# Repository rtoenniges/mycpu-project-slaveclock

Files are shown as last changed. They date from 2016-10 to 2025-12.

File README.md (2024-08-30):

# MyCPU_PRO_SCC
An extension for the [MyCPU](http://www.mycpu.eu/) from Dennis Kuschel to get the timesignal DCF77 and control a slave clock (https://en.wikipedia.org/wiki/Slave_clock)

## Hardware
- External module (Basic board)
- Rack extension (Clock control & DCF77 signal converting)

## Software
- scc.asm (Main program)
- sl60dcf77.asm (Library for DCF77 decoding (Can be found at https://github.com/rtoenniges/MyCPU_LIB_DCF77))

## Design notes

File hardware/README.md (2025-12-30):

# Hardware
## External module (Basic board without DCF77-Input)
This board only generates the alternating current to drive the clock.

## Rack Extension (DCF77-Input and slave-clock control)
This board is connected directly to the MyCPU-Backplane Bus.
It provides support to connect a DCF77-Receiver and generates the alternating
current to drive the clock.
Also it displays the status of the time synchronization and the active clock output.

**If you use this board and you have set the adress jumpers to the default position, you
have to change the "OUTPUT" declaration in "scc.asm" to '3500h'!**

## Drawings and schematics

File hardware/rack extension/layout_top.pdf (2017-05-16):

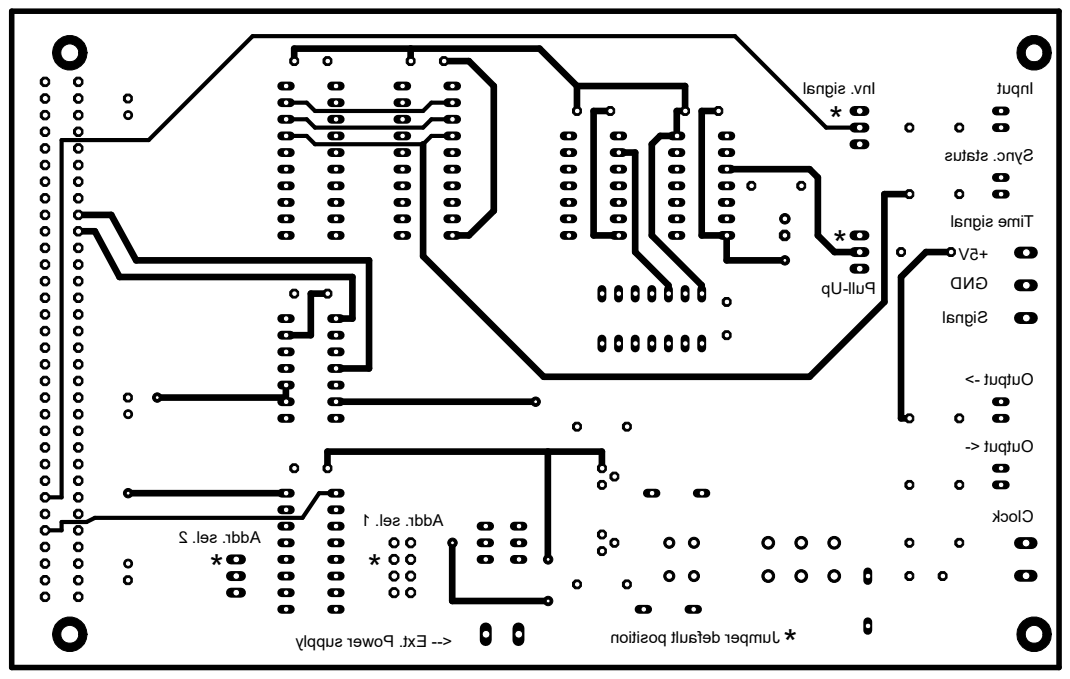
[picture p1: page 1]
Addr. sel. 1; Addr. sel. 2; Clock; Time signal; Pull-Up; Sync. status; Output ->; Output <-; GND; Signal

Inv. signal Input

* <-- Ext. Power supply

Jumper default position

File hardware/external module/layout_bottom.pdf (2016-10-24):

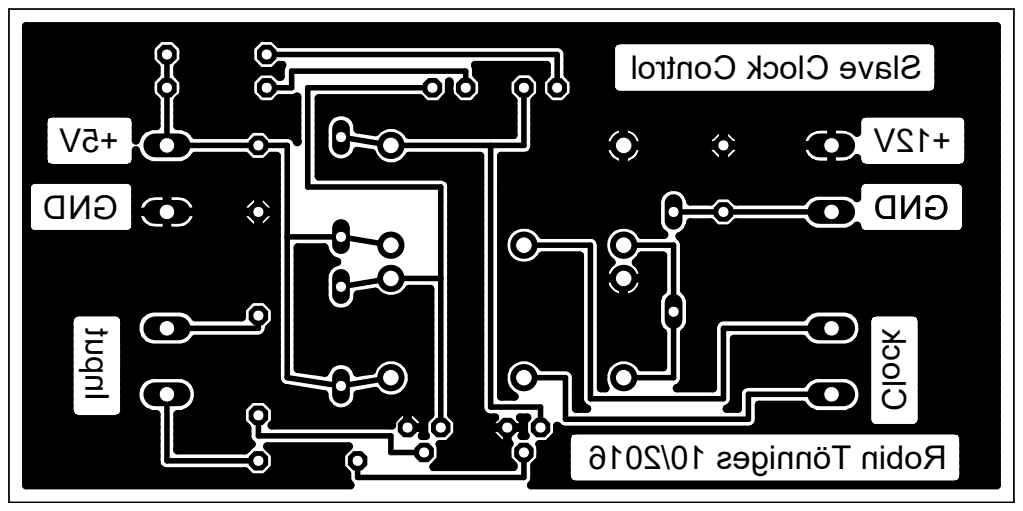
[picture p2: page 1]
+5V GNDInput; GND; +12VClock; Robin Tönniges 10/2016

Slave Clock Control

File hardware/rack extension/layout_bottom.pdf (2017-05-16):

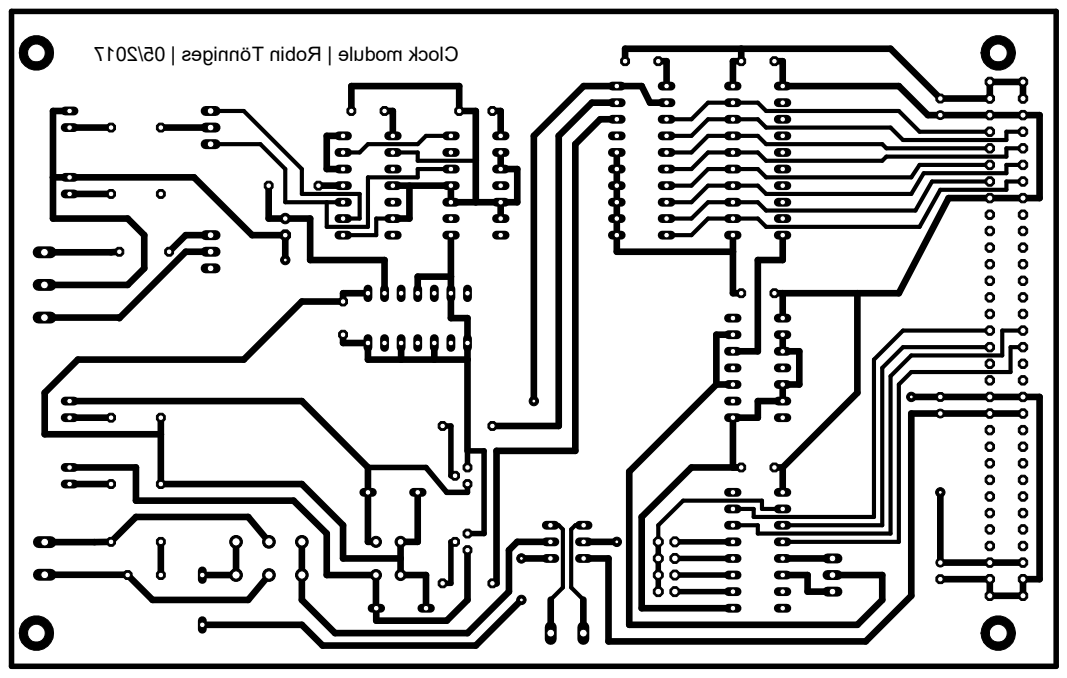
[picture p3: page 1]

Clock module | Robin Tönniges | 05/2017

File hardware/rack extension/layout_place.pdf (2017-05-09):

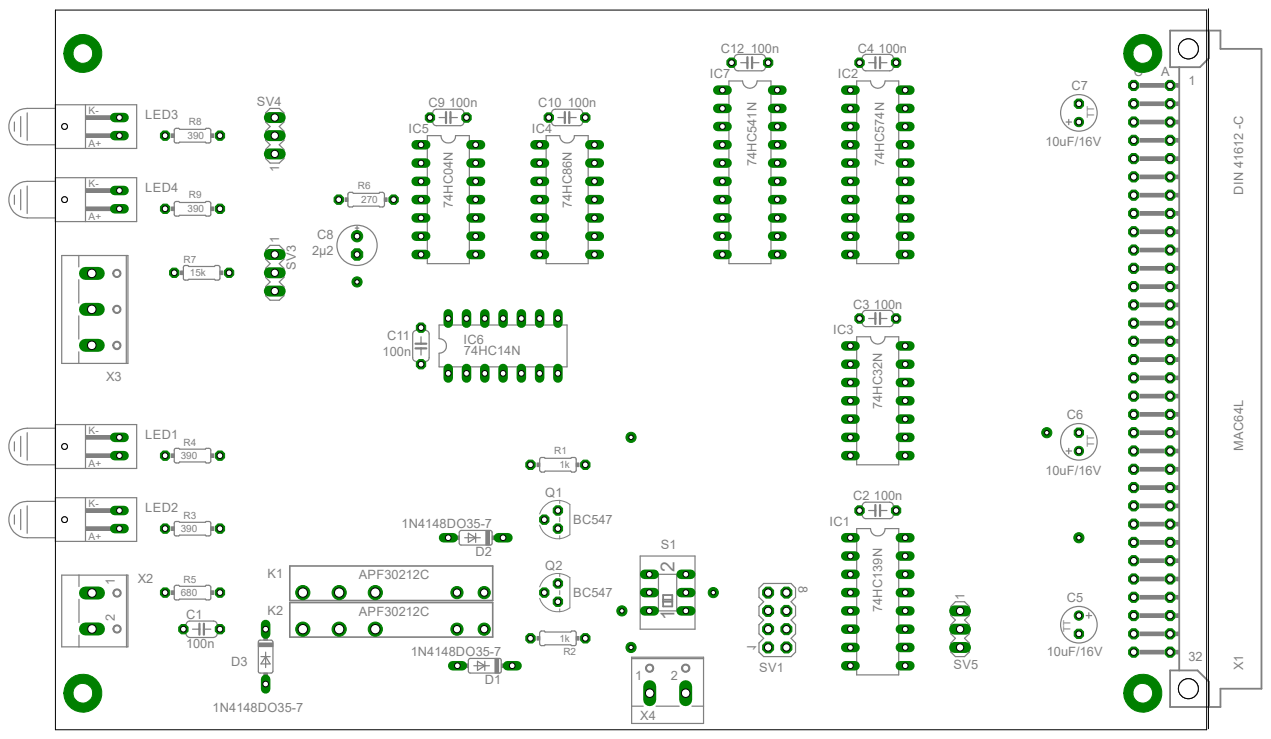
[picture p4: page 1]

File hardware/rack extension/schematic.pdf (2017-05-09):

e

## DCF77

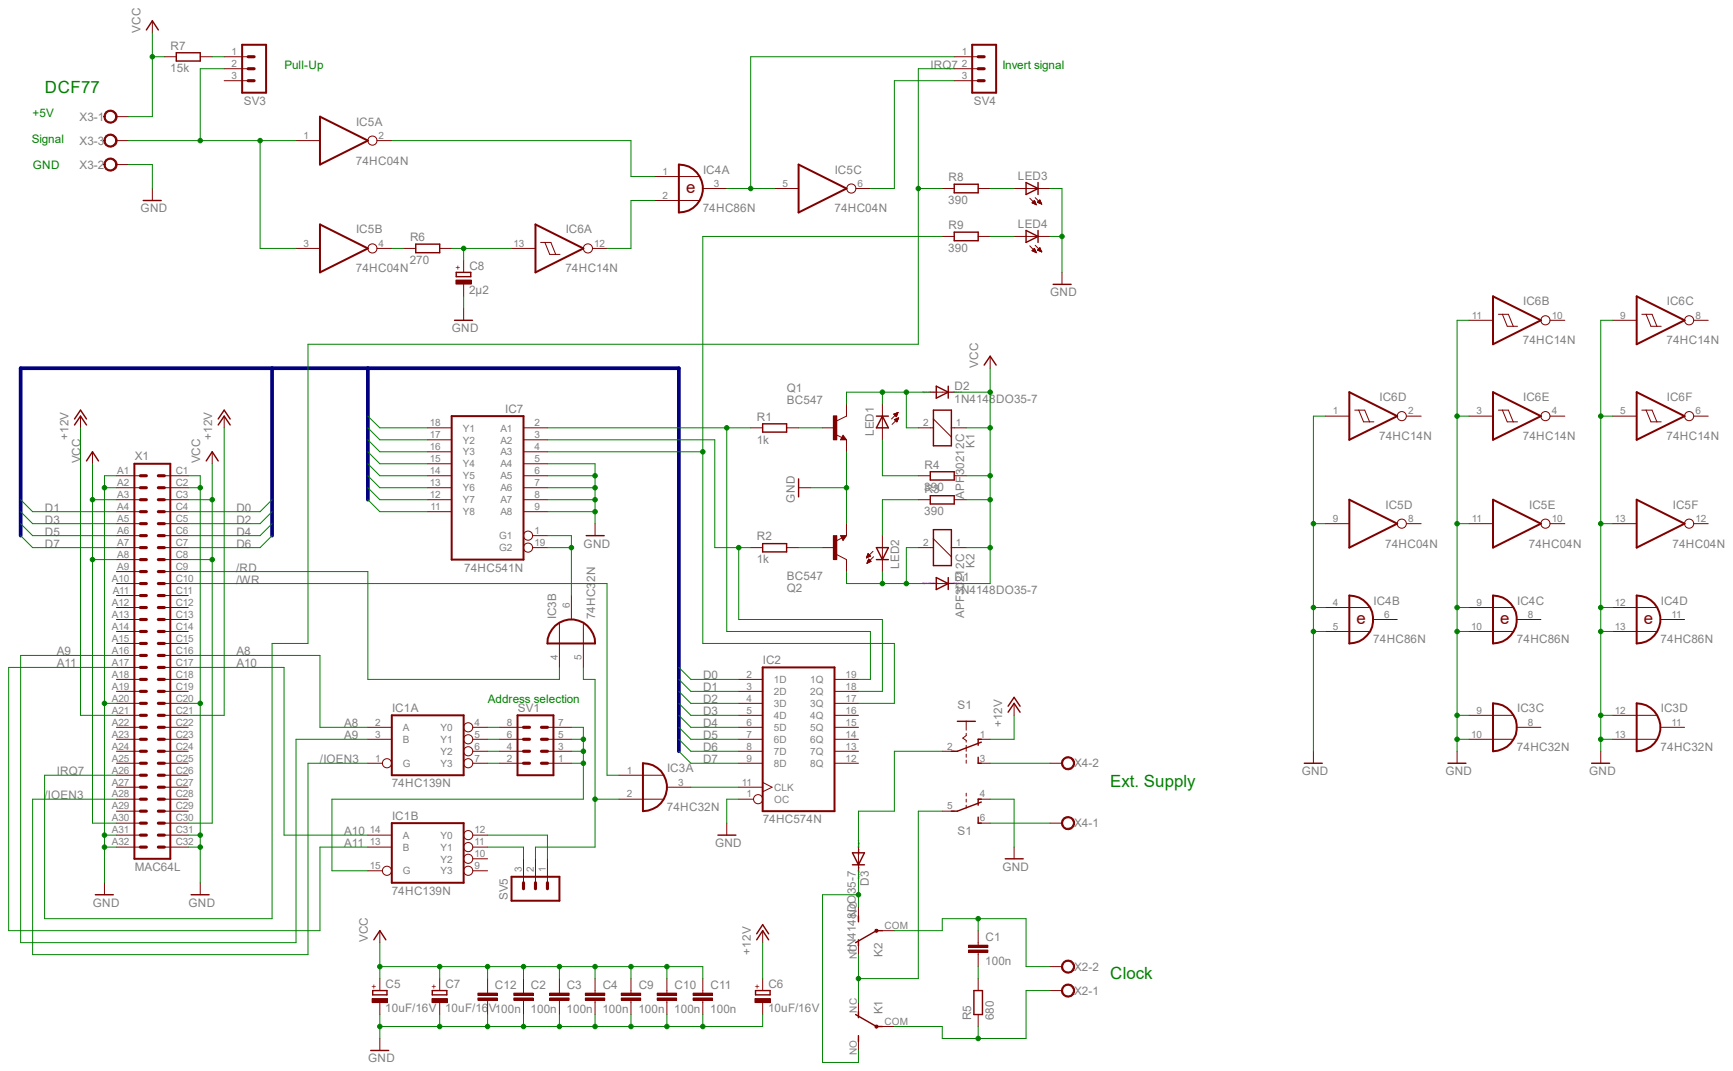
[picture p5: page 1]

C10 | /WR
C11 C12 C13 C14 C15 C16

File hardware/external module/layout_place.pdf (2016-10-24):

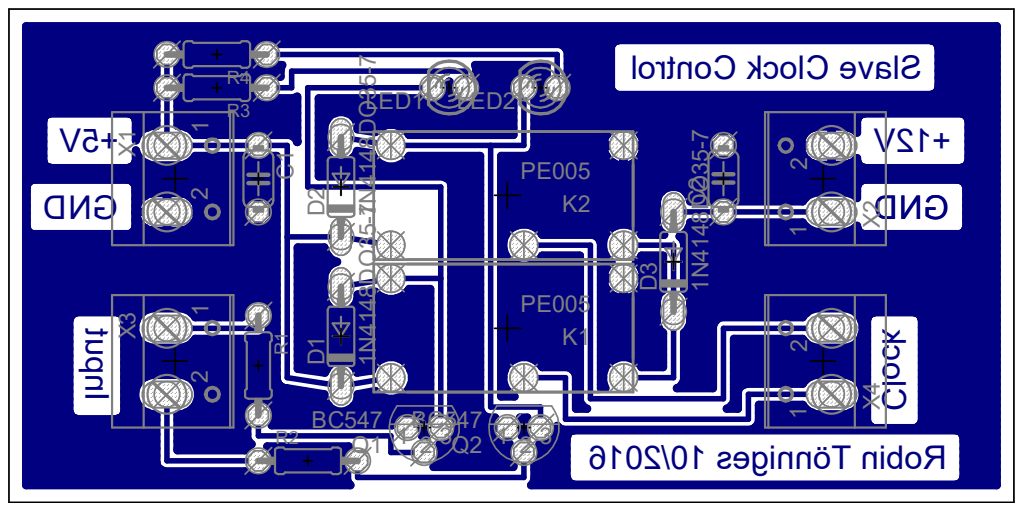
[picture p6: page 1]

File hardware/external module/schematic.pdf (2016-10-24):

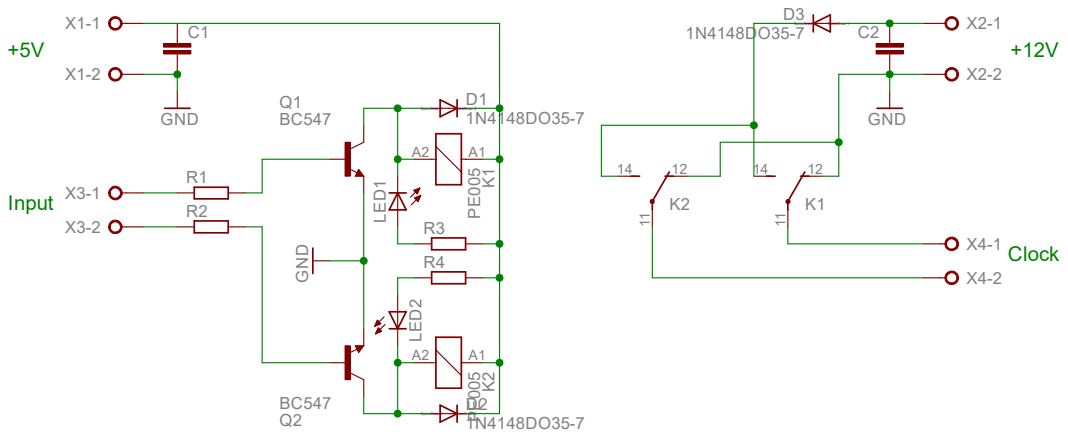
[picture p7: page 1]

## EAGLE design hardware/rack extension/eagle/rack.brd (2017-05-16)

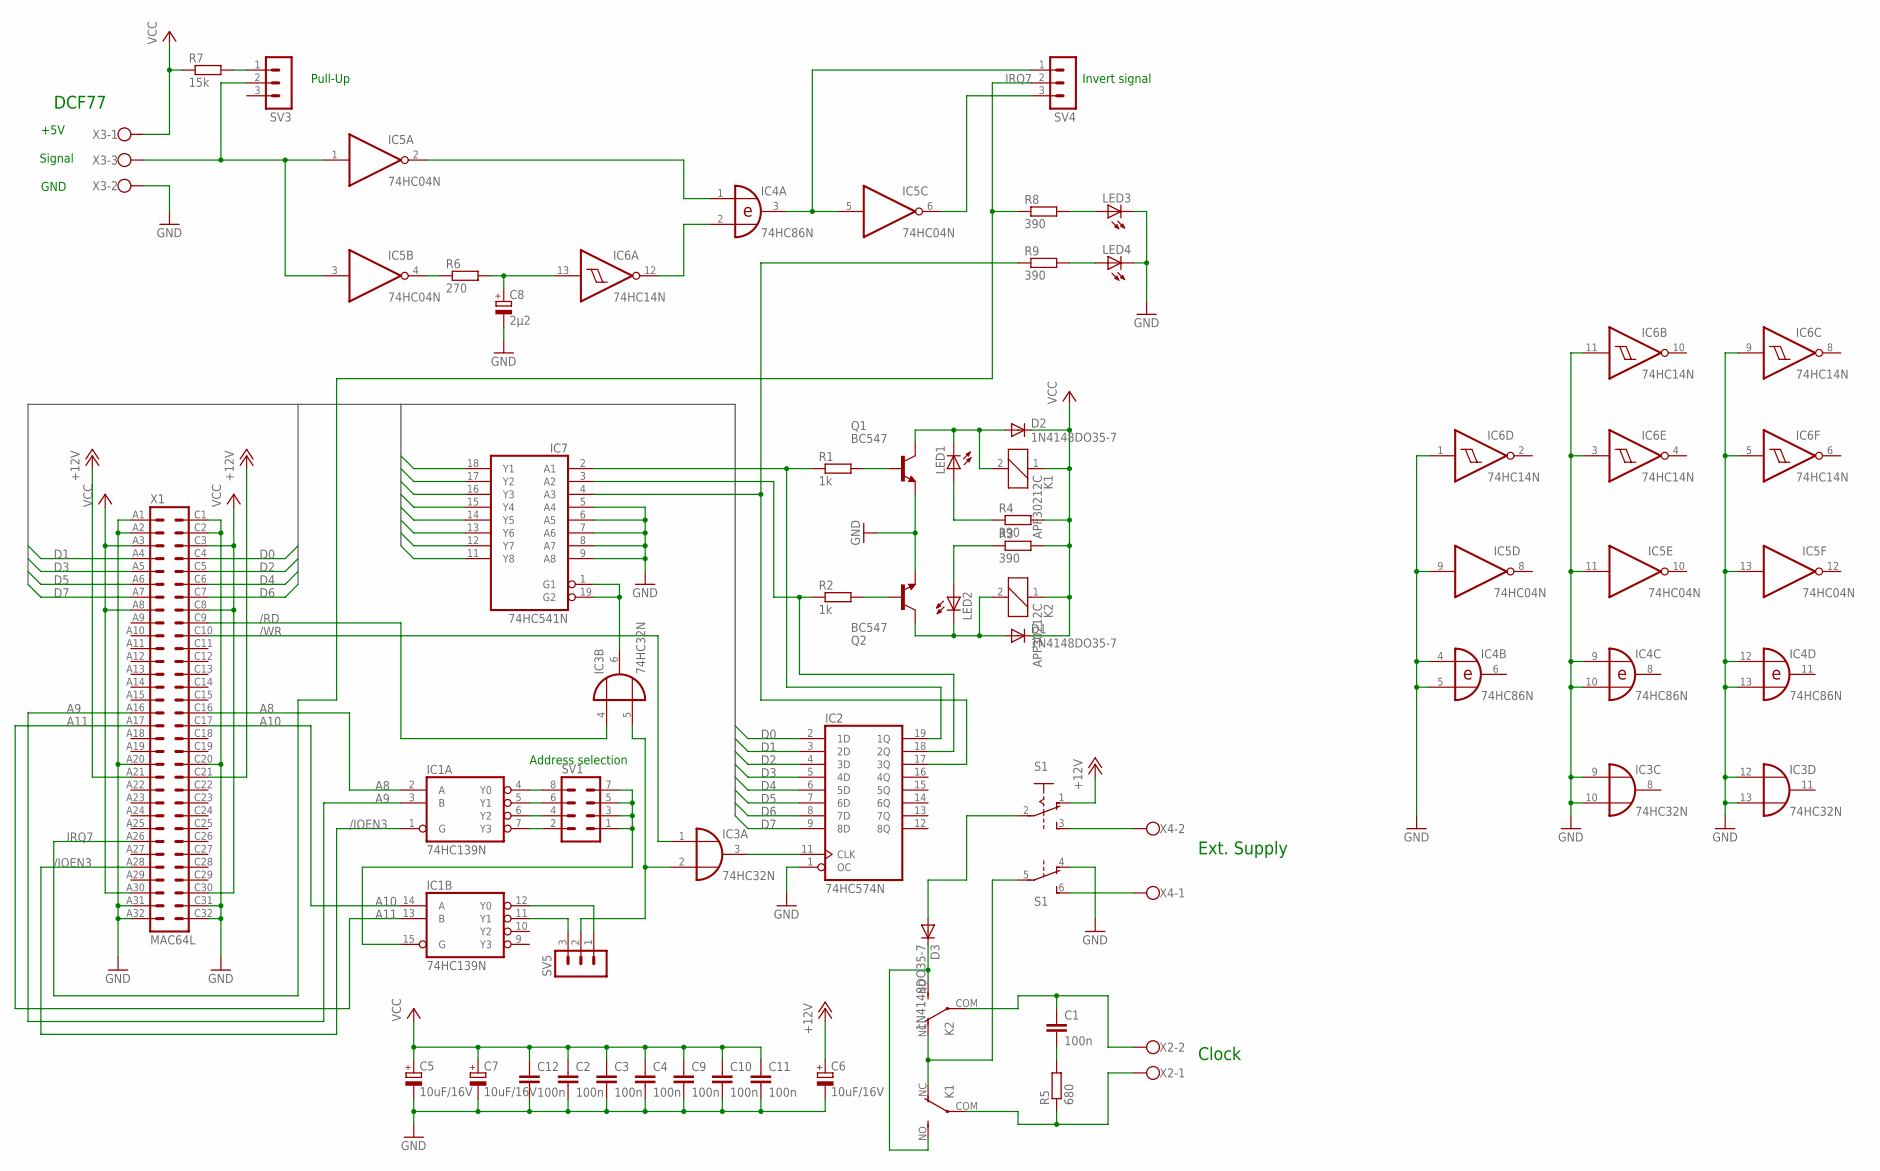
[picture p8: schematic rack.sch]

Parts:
C1, C2, C3, C4, C9, C10, C11, C12: 100n; C050-024X044
C5, C6, C7: 10uF/16V; TT2D5
C8: 2µ2; E2,5-6E
D1, D2, D3: 1N4148DO35-7; DO35-7
IC1: 74HC139N; DIL16
IC2: 74HC574N; DIL20
IC3: 74HC32N; DIL14
IC4: 74HC86N; DIL14
IC5: 74HC04N; DIL14
IC6: 74HC14N; DIL14
IC7: 74HC541N; DIL20
K1, K2: APF30212C
LED1, LED2, LED3, LED4: LEDB155; Q62902-B155
Q1, Q2: BC547; TO92
R1, R2: 1k; 0204/7
R3, R4, R8, R9: 390; 0204/7
R5: 680; 0204/7
R6: 270; 0204/7
R7: 15k; 0204/7
S1: A68-A31
SV1: MA04-2
SV3, SV4, SV5: MA03-1
X1: MAC64L
X2, X4: W237-102
X3: W237-103

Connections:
+12V: C6.+, S1.1 (O), X1.A21, X1.C21
/IOEN3: IC1.1 (G), X1.A28
/RD: IC3.4 (I0), X1.C9
/WR: IC3.1 (I0), X1.C10
A8: IC1.2 (A), X1.C16
A9: IC1.3 (B), X1.A16
A10: IC1.14 (A), X1.C17
A11: IC1.13 (B), X1.A17
D0: IC2.2 (1D), IC7.18 (Y1), X1.C4
D1: IC2.3 (2D), IC7.17 (Y2), X1.A4
D2: IC2.4 (3D), IC7.16 (Y3), X1.C5
D3: IC2.5 (4D), IC7.15 (Y4), X1.A5
D4: IC2.6 (5D), IC7.14 (Y5), X1.C6
D5: IC2.7 (6D), IC7.13 (Y6), X1.A6
D6: IC2.8 (7D), IC7.12 (Y7), X1.C7
D7: IC2.9 (8D), IC7.11 (Y8), X1.A7
GND: C2.2, C3.2, C4.2, C5.-, C6.-, C7.-, C8.-, C9.2, C10.2, C11.2, C12.2, IC1.8 (GND), IC2.1 (OC), IC2.10 (GND), IC3.7 (GND), IC3.9 (I0), IC3.10 (I1), IC3.12 (I0), IC3.13 (I1), IC4.4 (I0), IC4.5 (I1), IC4.7 (GND), IC4.9 (I0), IC4.10 (I1), IC4.12 (I0), IC4.13 (I1), IC5.7 (GND), IC5.9 (I), IC5.11 (I), IC5.13 (I), IC6.1 (I), IC6.3 (I), IC6.5 (I), IC6.7 (GND), IC6.9 (I), IC6.11 (I), IC7.5 (A4), IC7.6 (A5), IC7.7 (A6), IC7.8 (A7), IC7.9 (A8), IC7.10 (GND), LED3.K (C), LED4.K (C), Q1.1 (E), Q2.1 (E), S1.4 (O), X1.A1, X1.A2, X1.A20, X1.A31, X1.A32, X1.C1, X1.C2, X1.C20, X1.C31, X1.C32, X3.2
IRQ7: R8.1, SV4.2, X1.A26
unnamed: IC1.4 (Y0), SV1.8
unnamed: IC1.5 (Y1), SV1.6
unnamed: IC1.6 (Y2), SV1.4
unnamed: IC1.7 (Y3), SV1.2
unnamed: IC2.17 (3Q), IC7.4 (A3), R9.1
unnamed: IC1.11 (Y1), SV5.3
unnamed: IC1.12 (Y0), SV5.1
unnamed: IC1.15 (G), SV1.1, SV1.3, SV1.5, SV1.7
unnamed: IC2.11 (CLK), IC3.3 (O)
unnamed: Q1.2 (B), R1.2
unnamed: IC2.19 (1Q), IC7.2 (A1), R1.1
unnamed: IC2.18 (2Q), IC7.3 (A2), R2.1
unnamed: Q2.2 (B), R2.2
unnamed: D2.A, K1.2, LED1.K (C), Q1.3 (C)
unnamed: C1.2, R5.2
unnamed: D1.A, K2.2, LED2.K (C), Q2.3 (C)
unnamed: C1.1, K2.COM, X2.2
unnamed: LED1.A, R4.1
unnamed: LED2.A, R3.1
unnamed: K1.COM, R5.1, X2.1
unnamed: D3.C, K1.NO (S), K2.NO (S)
unnamed: IC5.4 (O), R6.1
unnamed: C8.+, IC6.13 (I), R6.2
unnamed: IC4.1 (I0), IC5.2 (O)
unnamed: IC4.2 (I1), IC6.12 (O)
unnamed: IC4.3 (O), IC5.5 (I), SV4.1
unnamed: K1.NC (O), K2.NC (O), S1.5
unnamed: R7.2, SV3.1
unnamed: IC5.1 (I), IC5.3 (I), SV3.2, X3.3
unnamed: IC5.6 (O), SV4.3
unnamed: LED3.A, R8.2
unnamed: S1.3 (S), X4.2
unnamed: S1.6 (S), X4.1
unnamed: D3.A, S1.2
unnamed: IC3.6 (O), IC7.1 (G1), IC7.19 (G2)
unnamed: IC3.2 (I1), IC3.5 (I1), SV5.2
unnamed: LED4.A, R9.2
VCC: C2.1, C3.1, C4.1, C5.+, C7.+, C9.1, C10.1, C11.1, C12.1, D1.C, D2.C, IC1.16 (VCC), IC2.20 (VCC), IC3.14 (VCC), IC4.14 (VCC), IC5.14 (VCC), IC6.14 (VCC), IC7.20 (VCC), K1.1, K2.1, R3.2, R4.2, R7.1, X1.A3, X1.A8, X1.A30, X1.C3, X1.C8, X1.C30, X3.1

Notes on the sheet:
Address selection
DCF77
+5V
GND
Signal
Clock
Pull-Up
Ext. Supply
Invert signal

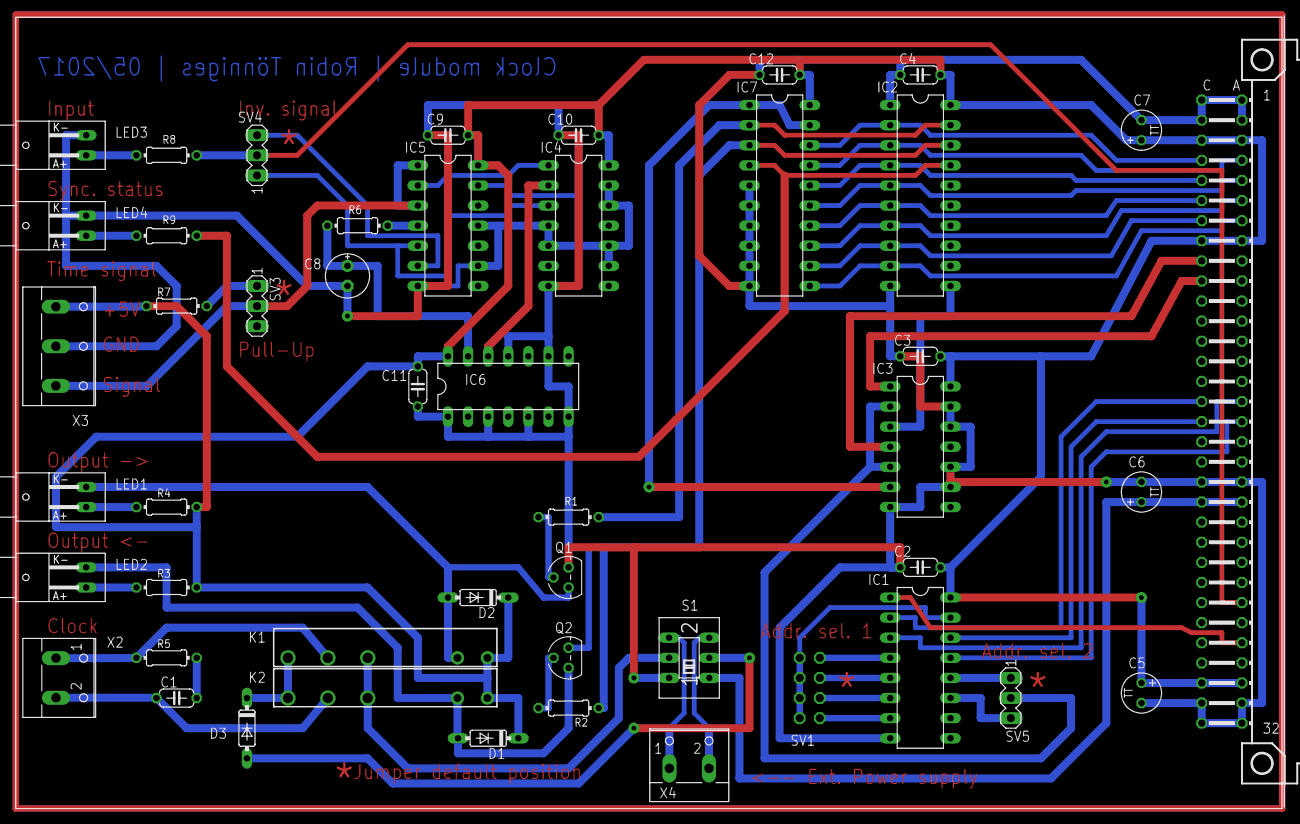
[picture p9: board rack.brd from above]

Board: 2 copper layers, 160.0 x 100.0 mm, 48 parts (1 on the bottom side), 56 nets.

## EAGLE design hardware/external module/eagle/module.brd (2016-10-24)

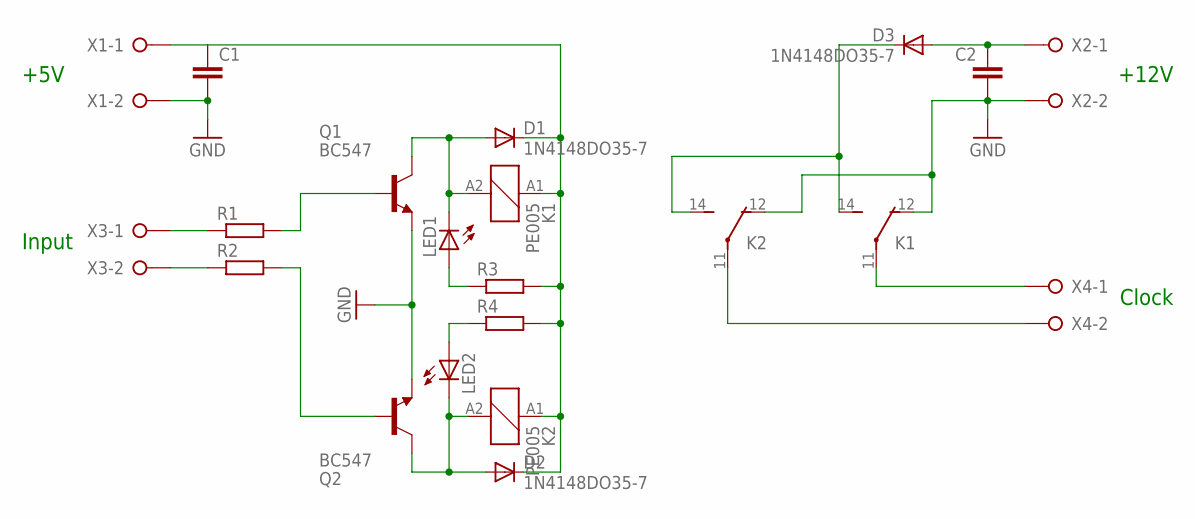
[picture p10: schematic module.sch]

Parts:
C1, C2: C-EU050-024X044; C050-024X044
D1, D2, D3: 1N4148DO35-7; DO35-7
K1, K2: PE005; PE
LED1, LED2: LED3MM
Q1, Q2: BC547; TO92
R1, R2, R3, R4: R-EU_0204/7; 0204/7
X1, X2, X3, X4: W237-02P; W237-132

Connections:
GND: C1.2, C2.2, K1.12 (O), K2.12 (O), Q1.1 (E), Q2.1 (E), X1.2, X2.2
unnamed: C2.1, D3.A, X2.1
unnamed: R1.1, X3.1
unnamed: K1.11, X4.1
unnamed: R2.1, X3.2
unnamed: K2.11, X4.2
unnamed: Q1.2 (B), R1.2
unnamed: D1.A, K1.A2 (2), LED1.K (C), Q1.3 (C)
unnamed: D2.A, K2.A2 (2), LED2.K (C), Q2.3 (C)
unnamed: C1.1, D1.C, D2.C, K1.A1 (1), K2.A1 (1), R3.2, R4.2, X1.1
unnamed: LED1.A, R3.1
unnamed: Q2.2 (B), R2.2
unnamed: D3.C, K1.14 (S), K2.14 (S)
unnamed: LED2.A, R4.1

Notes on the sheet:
+5V
+12V
Input
Clock

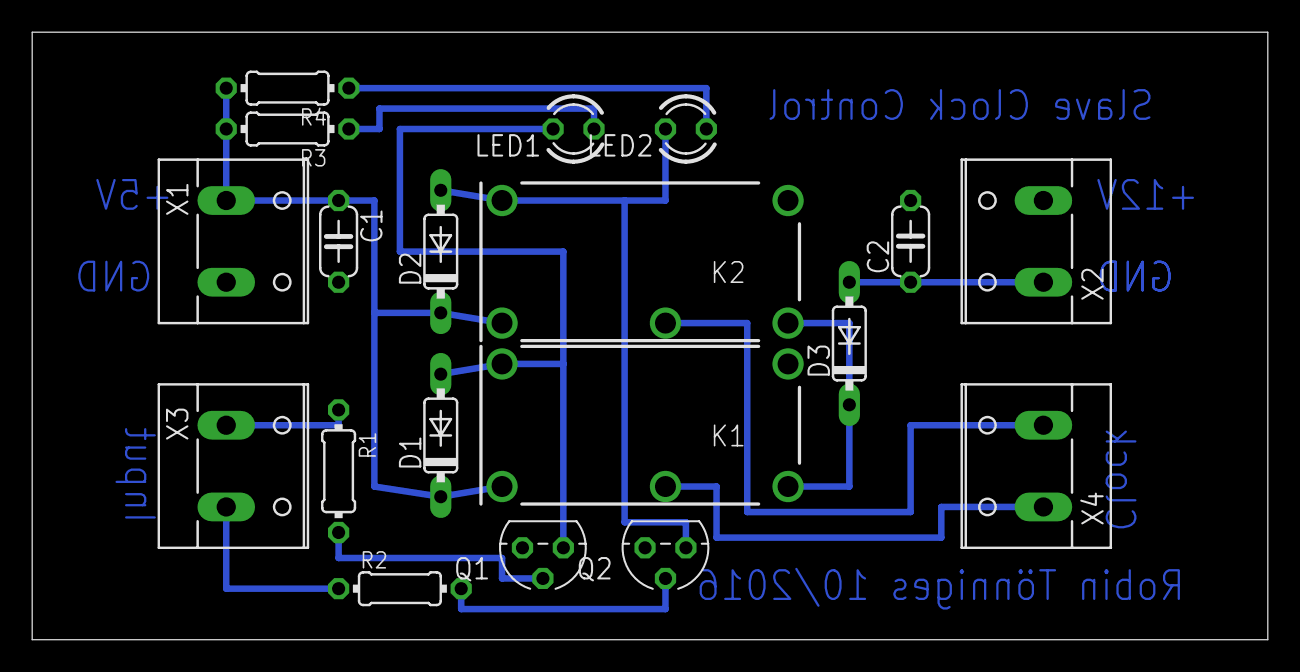
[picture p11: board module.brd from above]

Board: 2 copper layers, 76.8 x 37.8 mm, 19 parts (0 on the bottom side), 14 nets.

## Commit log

2016-10-24 First release
    [scc.brd, scc.sch]
2016-10-29 New Hardware
    [module.brd, module.sch, rack.brd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]
2016-11-10 Bad fail in rack hardware
    The switch S1 was connected wrong so the change from internal to
    external supply didnt work.
    [rack.brd, rack.sch]
2016-11-10 Switched 74AC parts to 74HC
2017-04-06 Layout updated
    Updated layout from rack extension
    [rack.brd, rack.sch]
2017-05-03 Litte changes in schematic and layout
    Added further description and fixed an naming issue in schmematic
    [rack.brd, rack.sch]
2017-05-09 Value of PullUp from1k to 15k
    [rack.brd, rack.sch]
2017-05-16 Little layout update
    [rack.brd]
